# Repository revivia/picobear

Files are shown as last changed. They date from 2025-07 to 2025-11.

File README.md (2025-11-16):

# PicoBear

Meet PicoBear! \
Have you ever set your own screen time just to find yourself pressing ignore every time you receive a reminder? Or have you downloaded a productivity app that locks you out of social media and find that it never helps?

Our project is a lockbox with a timer, display, LEDs, and ultrasonic sensor, and is the ultimate productivity tool! \
The hour and minutes buttons are used to set a timer, and the timer is started by pressing the set button. The display counts down the timer, telling you how long to wait. If you reach for your phone before the timer is up, the LEDs will flash red.

<p align="center">
  Description 3
</p>

Watch the demo [here](https://youtu.be/nj33L2LZXyw)! 

We made this project to reduce screen usage and improve productivity. Not only does this increase productivity by minimizing distractions, it also helps clear your mind and take effective breaks without screens.

<table align="center">
  <tr>
    <td align="center">
      Description 1<br/>
      <sub>Wiring Diagram</sub>
  </tr>
</table>

The case was made using
[Onshape](https://cad.onshape.com/documents/da1e6013c94abb4d44284d02/w/a4168b892938869d8b51b26b/e/949c48882b160e3986ef9565).

## BOM
x1 [Raspberry Pi Pico](https://www.pishop.us/product/raspberry-pi-pico/?src=raspberrypi) \
x20 [Jumper Wires](https://a.co/d/7m2MJUb) \
x1 [Tower Pro Micro Servo](https://www.pishop.us/product/sg90-180-degrees-9g-micro-servo-motor-tower-pro/) \
x3 [Cherry MX Switches](https://www.pishop.us/product/sg90-180-degrees-9g-micro-servo-motor-tower-pro/) \
x1 [TM1637 4 Digit 7 Segment Display](https://www.aliexpress.us/item/3256804068613221.html?) \

x1 [LED strip](https://a.co/d/1G6YokX)
x1 [Ultrasonic sensor](https://a.co/d/3tDz4aN)
x3 Keycaps (Custom Made - 3D printable files in Production) \
x1 USB cable - Any A to C

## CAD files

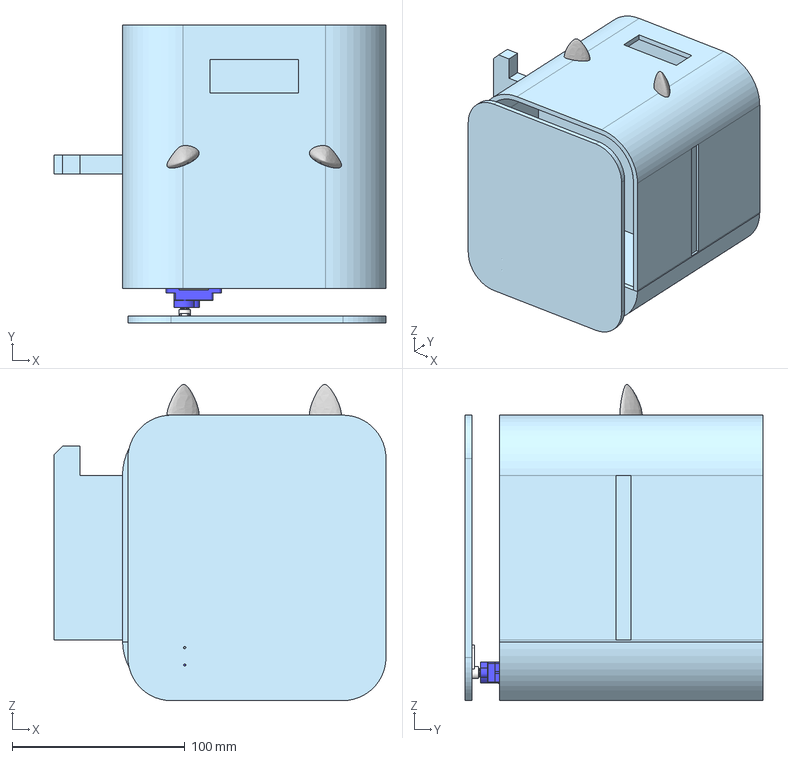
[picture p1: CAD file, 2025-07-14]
CAD/Assembly.step
192.0 x 172.4 x 182.9 mm
SG90 - Micro Servo 9g - Tower Pro.1_Pe�a x 13
SG90 - Micro Servo 9g - Tower Pro.2_Pe�a
SG90 - Micro Servo 9g - Tower Pro.6_BS EN ISO 7045 - M2 x 4 - Z - 4S
SG90 - Micro Servo 9g - Tower Pro.5_BS EN ISO 7045 - M2 x 8 - Z - 8S

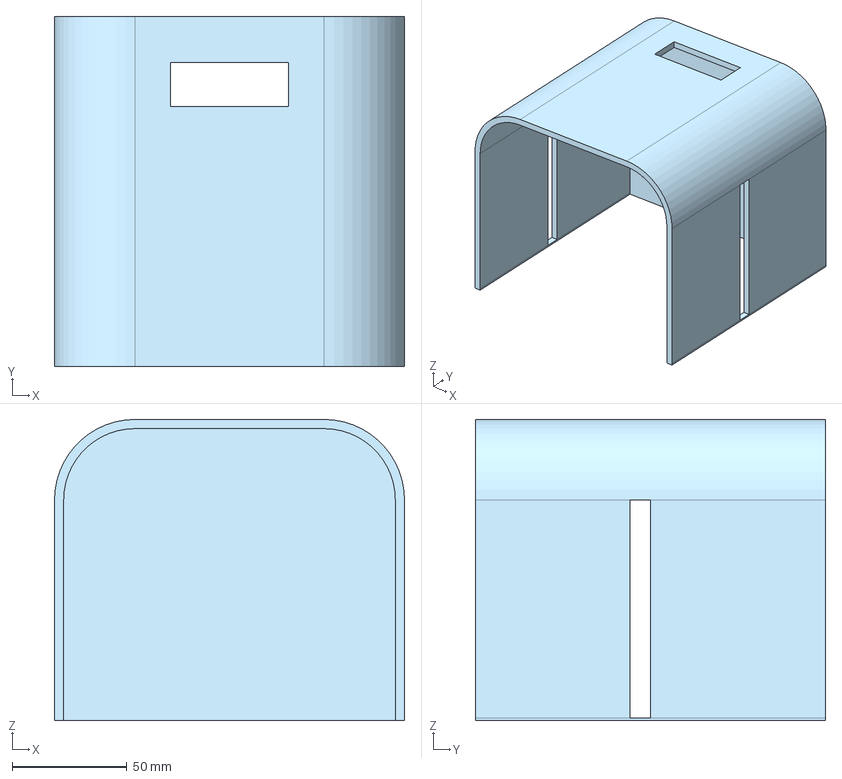
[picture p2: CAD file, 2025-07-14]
Production/Case/Main Body Copy 1 - Part 1 (4).step
152.4 x 152.4 x 131.1 mm

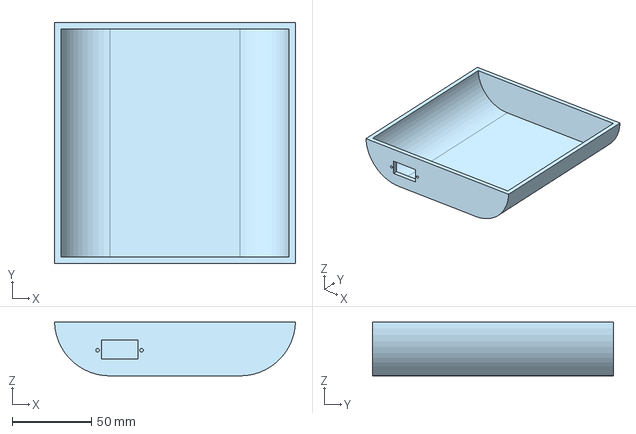
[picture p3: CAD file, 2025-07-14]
Production/Case/Main Body Copy 1 - Part 2 (2).step
152.4 x 152.4 x 34.0 mm

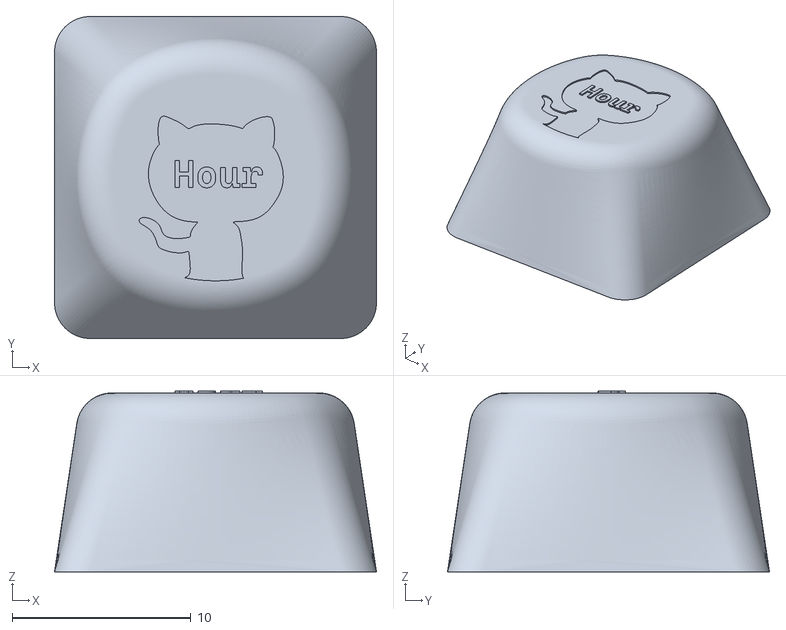
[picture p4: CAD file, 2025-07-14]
Production/Custom Keycaps/Hour Keycap.stl
18.0 x 18.0 x 10.1

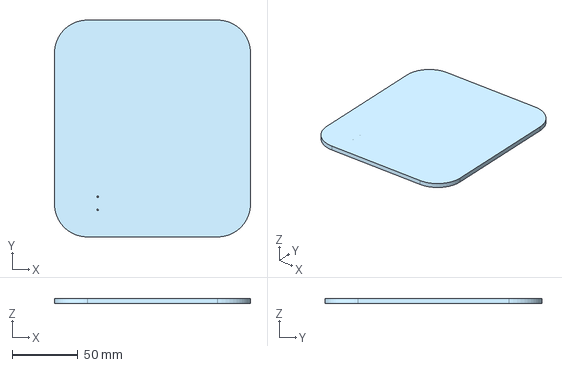
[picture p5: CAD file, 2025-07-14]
Production/Case/Side - Part 1 (1).step
149.2 x 165.1 x 4.00 mm

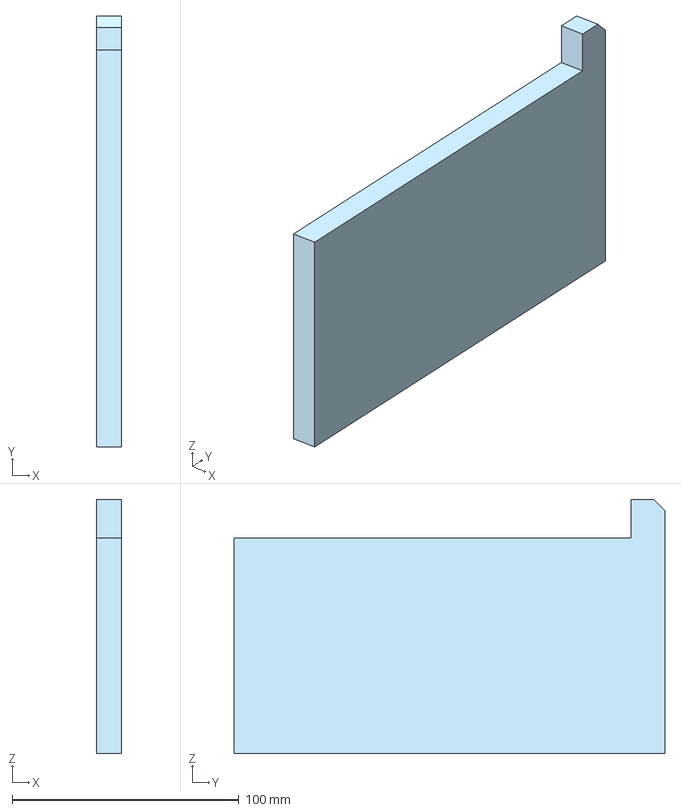
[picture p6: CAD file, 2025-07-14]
Production/Case/Slider - Part 1 (1).step
10.8 x 190.0 x 112.2 mm

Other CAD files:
Production/Custom Keycaps/Set Keycap.stl
Production/Custom Keycaps/Minute Keycap.stl

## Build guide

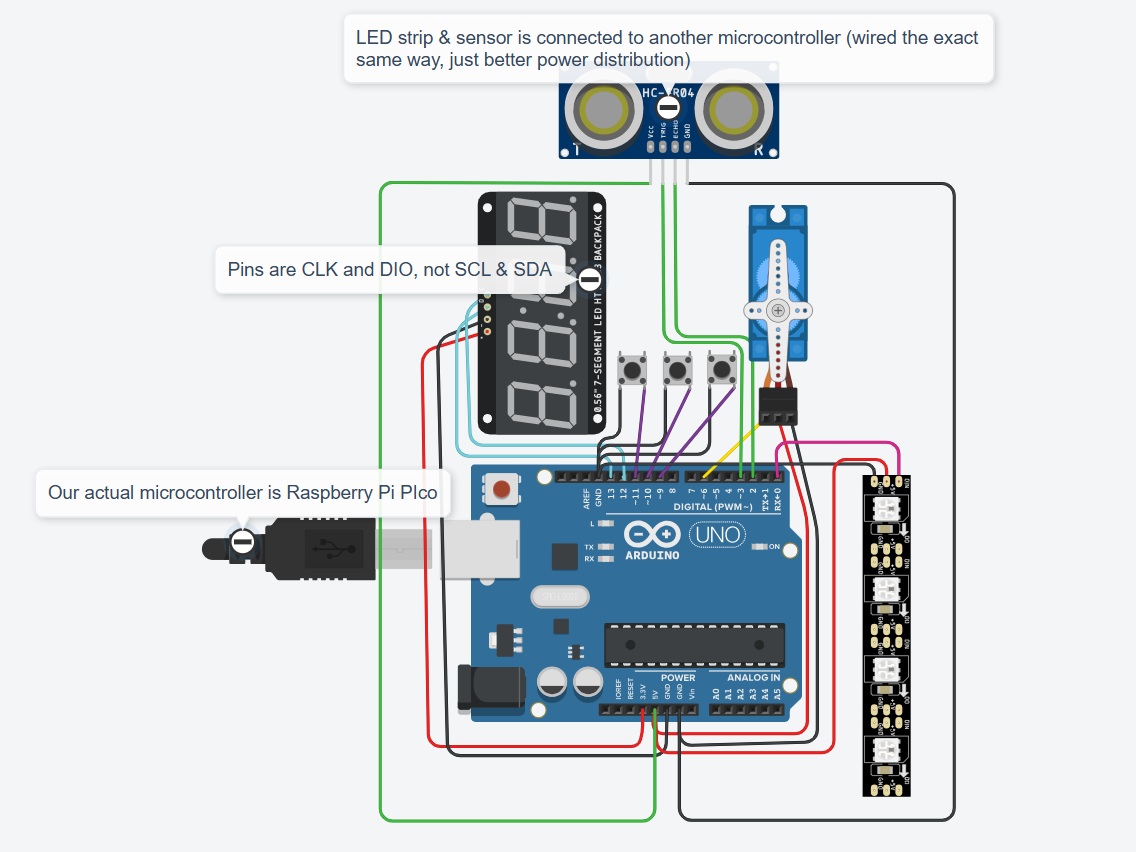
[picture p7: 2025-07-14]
Production/wiring.png

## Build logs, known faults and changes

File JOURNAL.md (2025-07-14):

# Journal
Total Time: 33 Hours
## July 11, 2025
First, we brainstormed project ideas and originally decided on an Inconvenience Alarm, where it forces you to wake up due to its difficult snooze function. \
We picked out components and soldered the Raspberry Pi Pico. \
We also created a CAD model for the case.

<p align="center">
  Description 1
  Description 2
</p>
Time Spent: 3 Hours

## July 12, 2025
Crashed out because unfortunately, we didn’t have motor drivers and we learned that DIY-ing an H bridge is very hard :( We got the motor to spin but it short circuited. \
We decided to abandon the moving alarm and do a timer system instead. We soldered the Cherry MX switches & coded it to display the timer on the Console Log. We did this just in time to demo. \
Then, we remade the CAD for the timer design & created custom keycaps. We wired up the TM1637 display and made it display the countdown.

<p align="center">
  Description 3
  Description 4
  Description 5
</p>
Time Spent: 15 Hours

## July 13, 2025
We got the front part of our box printed. We wired up the neopixels and ultrasonic sensor and successfully got it to be hot pink! \
2 servo motors crashed the circuit so we changed it to 1 motor. It didn’t work for the majority of the day until right before the evening demos where we were able to demo again. \
We finished the code for the lockbox system and continued working on additional features, like the sensor and LED.
<p align="center">
  Description 6
  Description 7
</p>
Time Spent: 15 Hours

## July 14, 2025
Final stretch! Got the sensor and LED working and mounted it to a different breadboard. The high current from the sirvo caused the circuit to stop working, so we disconnected it and are relying on the sensors to stop people from reaching for their phones. The front plate did not 3D print, so we made elements out of cardboard. We continued to test and mounted the keyswitches, LEDs and sensor.

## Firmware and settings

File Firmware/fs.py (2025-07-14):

from machine import Pin, PWM
import time

# ===== TM1637 4-digit display class =====
class TM1637:
    def __init__(self, clk_pin, dio_pin):
        self.clk = Pin(clk_pin, Pin.OUT)
        self.dio = Pin(dio_pin, Pin.OUT)
        self.digits = [0x3f, 0x06, 0x5b, 0x4f, 0x66,
                       0x6d, 0x7d, 0x07, 0x7f, 0x6f, 0x00]

    def start(self):
        self.dio.value(1)
        self.clk.value(1)
        self.dio.value(0)
        self.clk.value(0)

    def stop(self):
        self.clk.value(0)
        self.dio.value(0)
        self.clk.value(1)
        self.dio.value(1)

    def write_byte(self, b):
        for i in range(8):
            self.clk.value(0)
            self.dio.value((b >> i) & 1)
            self.clk.value(1)
        self.clk.value(0)
        self.dio.init(Pin.IN)
        self.clk.value(1)
        self.dio.init(Pin.OUT)
        self.clk.value(0)

    def display(self, nums, colon=False):
        self.start()
        self.write_byte(0x40)
        self.stop()

        self.start()
        self.write_byte(0xC0)
        for i, num in enumerate(nums):
            seg = self.digits[num] if num < len(self.digits) else 0x00
            if colon and i == 1:
                seg |= 0x80
            self.write_byte(seg)
        self.stop()

        self.start()
        self.write_byte(0x88 + 7)
        self.stop()

# ===== Setup =====
display = TM1637(2, 3)	

btn_hour = Pin(19, Pin.IN, Pin.PULL_UP)
btn_minute = Pin(18, Pin.IN, Pin.PULL_UP)
btn_start = Pin(20, Pin.IN, Pin.PULL_UP)

servo3 = None

def init_servo():
    global servo3
    servo3 = PWM(Pin(10))
    servo3.freq(50)

def deinit_servo():
    global servo3
    if servo3:
        servo3.deinit()
        servo3 = None

def set_servo_angle(angle):
    if servo3 is None:
        return
    min_duty = 1638
    max_duty = 8192
    duty = min_duty + (max_duty - min_duty) * angle / 180
    servo3.duty_u16(int(duty))

# ===== Timer State =====
hours = 0
minutes = 0
timer_running = False
last_minute_tick = time.ticks_ms()

# ===== Debounce =====
debounce_ms = 200
prev_hour = prev_minute = prev_start = True
last_hour_press = last_minute_press = last_start_press = 0

# ===== Main Loop =====
while True:
    now = time.ticks_ms()

    # --- BUTTON HANDLING ---
    curr_hour = btn_hour.value()
    curr_minute = btn_minute.value()
    curr_start = btn_start.value()

    if prev_hour and not curr_hour and time.ticks_diff(now, last_hour_press) > debounce_ms:
        hours = (hours + 1) % 100
        last_hour_press = now

    if prev_minute and not curr_minute and time.ticks_diff(now, last_minute_press) > debounce_ms:
        minutes = (minutes + 1) % 60
        last_minute_press = now

    if prev_start and not curr_start and time.ticks_diff(now, last_start_press) > debounce_ms:
        timer_running = not timer_running
        last_start_press = now

        if timer_running:
            print("Timer started")
            init_servo()
            set_servo_angle(90)
            time.sleep(0.5)
            deinit_servo()
        else:
            print("Timer stopped manually")

    prev_hour = curr_hour
    prev_minute = curr_minute
    prev_start = curr_start

    # --- TIMER LOGIC (non-blocking) ---
    if timer_running and time.ticks_diff(now, last_minute_tick) >= 60000:  # 60 sec passed
        last_minute_tick = now
        if minutes == 0:
            if hours == 0:
                timer_running = False
                print("Timer finished")
                init_servo()
                set_servo_angle(0)
                time.sleep(0.5)
                deinit_servo()
            else:
                hours -= 1
                minutes = 59
        else:
            minutes -= 1

    # --- DISPLAY ---
    colon_state = (now // 500) % 2 == 0
    display.display([hours // 10, hours % 10, minutes // 10, minutes % 10], colon=colon_state)

    time.sleep(0.01)  # smooth loop

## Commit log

2025-07-14 Added CAD & Production files
    [Assembly.step, Hour Keycap.stl, Minute Keycap.stl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]
2025-07-14 Add case
    [Main Body Copy 1 - Part 1 (4).step, Main Body Copy 1 - Part 2 (2).step, Side - Part 1 (1).step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]
2025-07-14 add wiring diagram
